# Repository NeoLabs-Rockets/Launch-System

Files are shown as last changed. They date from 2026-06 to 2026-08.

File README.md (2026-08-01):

<div align="center">

# NeoLabs-Rockets Launch System

NeoLabs Rockets Logo

**Rocket systems by NeoLabs — ESP32 launch controller + Node.js mission dashboard.**



---

[🚀 Mission Dashboard](#mission-dashboard) · [🛰️ Launch System](#launch-system)

[Compatible with NeoLabs-Rockets launch platform](https://github.com/NeoLabs-Rockets/Launch-Platform)

---

</div>

## Mission Dashboard

A single-page web app that runs on a laptop at the launch site and connects to a custom PCB over Bluetooth (BLE).

### Features

| Feature | Description |
|---|---|
| **Launch Console** | Guided 4-step wizard: Connect → Checklist → Arm → Countdown. BLE connects once and drives every view. |
| **Live BLE keepalive** | Active ping every 2 s detects silent drops; heartbeat during countdown proves the link every 700 ms. |
| **Weather & airspace** | Live wind, temperature, precipitation, and ADS-B aircraft corridor check with GO / HOLD / NO-GO badge. |
| **Location Finder** | OSM-based candidate scorer — rates grid points against roads, highways (big exclusion), settlements, power lines, water, trees, airports, and open fields. Green-only results on the map; links open Google Earth satellite view. |
| **Camera overlay** | Cinematic broadcast HUD with live T−countdown ring (bottom-right), T+ elapsed after ignition, BLE and weather telemetry. |
| **Cross-device camera** | Phone subscribes to the laptop's SSE stream and receives the countdown + BLE state in real time — no BLE on the phone needed. |



---

## Launch System

BLE launch controller — see [`/LaunchSystem`](LaunchSystem/).




One-layer PCB - no bridges

---

<div align="center">

*Made with ❤️ by [Neo](https://github.com/neooriginal) · [NeoLabs Systems](https://github.com/NeoLabs-Systems)*

</div>

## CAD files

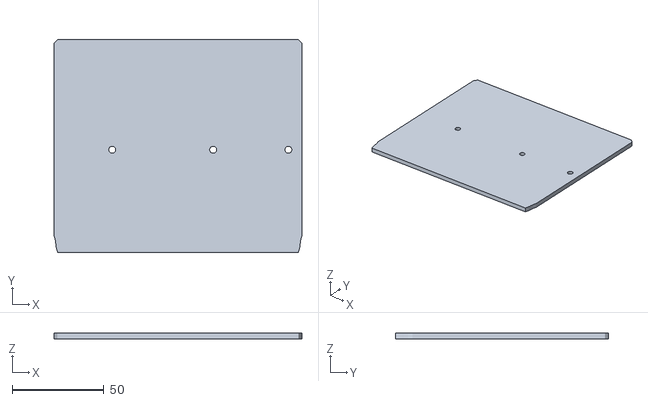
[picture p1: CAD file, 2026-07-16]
LaunchSystem/LID-optional.stl
135.1 x 116.1 x 3.00

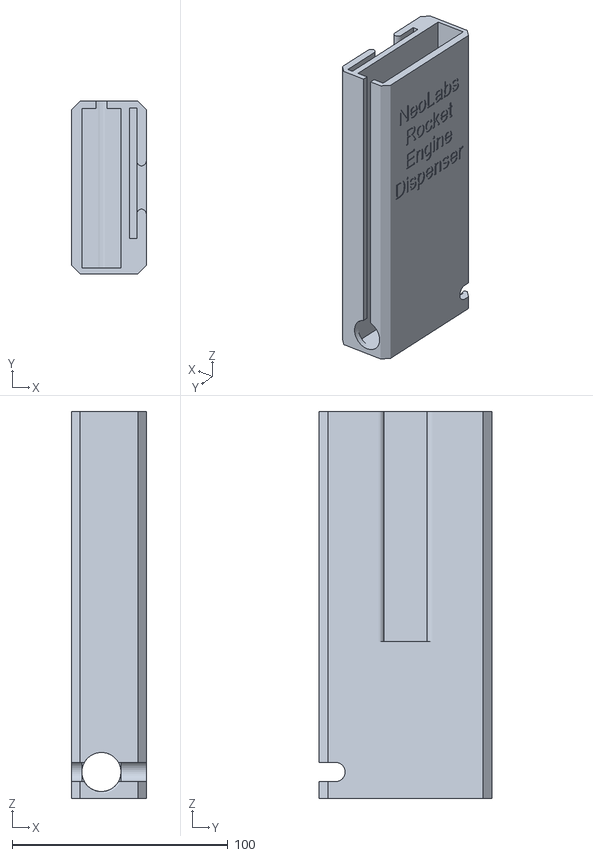
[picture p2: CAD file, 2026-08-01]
Rocket-Engine-Dispenser.stl
34.7 x 80.0 x 179.4

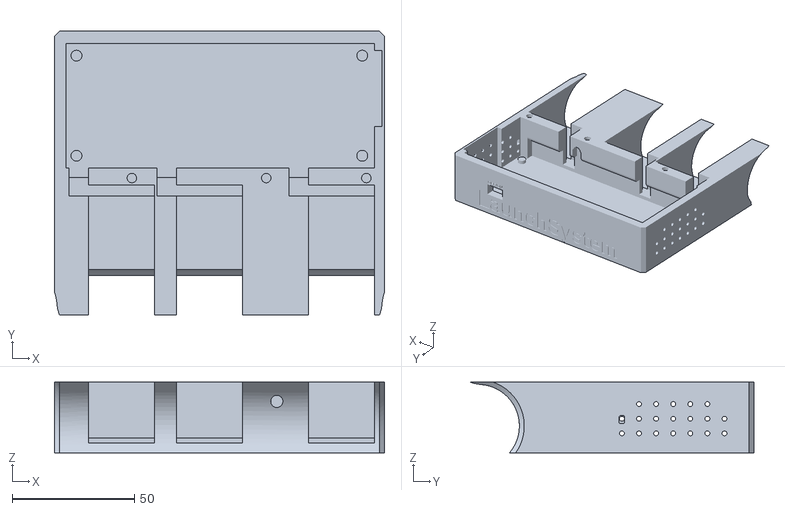
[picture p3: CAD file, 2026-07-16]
LaunchSystem/Body.stl
135.1 x 116.1 x 29.0

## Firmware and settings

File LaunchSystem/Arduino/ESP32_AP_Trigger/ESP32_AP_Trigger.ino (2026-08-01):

/* NeoLabs Rockets launch controller — BLE only. */
#include <NimBLEDevice.h>
#include <Adafruit_NeoPixel.h>
#include <Update.h>
#include <esp_ota_ops.h>
#include <mbedtls/sha256.h>

#define RELAY_PIN 23
#define CONTINUITY_PIN 34
#define CONTINUITY_ACTIVE_LEVEL LOW
#define STATUS_LED_PIN 26
#define ARM_PIN -1
#define BUZZER_PIN 33
#define TEMPERATURE_PIN 35
#define LAUNCH_CODE "123456"  // must match MissionDashboard LAUNCH_CODE
#define MAX_ATTEMPTS 10
#define TRIGGER_MS 2000UL
#define COUNTDOWN_TIMEOUT_MS 3000UL
#define CONTINUITY_DEBOUNCE_MS 60UL
#define TEMPERATURE_SAMPLE_INTERVAL_MS 1000UL
#define NTC_SAMPLE_COUNT 16
#define NTC_SUPPLY_MV 3300.0f
#define NTC_FIXED_RESISTOR_OHMS 10000.0f
#define NTC_NOMINAL_RESISTANCE_OHMS 10000.0f
#define NTC_NOMINAL_TEMPERATURE_K 298.15f
#define NTC_BETA 3950.0f
#define MAX_SAFE_TEMPERATURE_C 40.0f
#define BUZZER_MIN_FREQUENCY_HZ 1800U
#define BUZZER_MAX_FREQUENCY_HZ 4200U
#define BUZZER_FREQUENCY_STEP_HZ 120U
#define BUZZER_STEP_INTERVAL_MS 25UL
#define BUZZER_DISARM_MS 700UL
#define BUZZER_ARM_MS 900UL
#define BUZZER_TRIGGER_MS 1600UL
#define OTA_IDLE_TIMEOUT_MS 15000UL
#define OTA_REBOOT_DELAY_MS 1200UL
#define OTA_PROGRESS_INTERVAL_BYTES 2560UL

#ifndef FIRMWARE_VERSION
#define FIRMWARE_VERSION "3.0.0"
#endif

static NimBLEUUID SERVICE_UUID("8f3a0001-7b2f-4f8a-9d0e-0c5b6f0a1000");
static NimBLEUUID COMMAND_UUID("8f3a0002-7b2f-4f8a-9d0e-0c5b6f0a1000");
static NimBLEUUID STATUS_UUID ("8f3a0003-7b2f-4f8a-9d0e-0c5b6f0a1000");
static NimBLEUUID OTA_CONTROL_UUID("8f3a0004-7b2f-4f8a-9d0e-0c5b6f0a1000");
static NimBLEUUID OTA_DATA_UUID   ("8f3a0005-7b2f-4f8a-9d0e-0c5b6f0a1000");
static NimBLEUUID OTA_STATUS_UUID ("8f3a0006-7b2f-4f8a-9d0e-0c5b6f0a1000");
static const char BLE_NAME[] = "NeoLabs Launch Controller";
static const char CURRENT_FIRMWARE_VERSION[] = FIRMWARE_VERSION;

NimBLECharacteristic* statusChar = nullptr;
NimBLECharacteristic* otaStatusChar = nullptr;
Adafruit_NeoPixel statusPixel(1, STATUS_LED_PIN, NEO_GRB + NEO_KHZ800);
bool armed = false, firing = false, countdown = false, locked = false;
bool continuity = false, continuityRaw = false, continuityOverride = false;
bool temperatureOverride = false;
bool otaActive = false, otaShaInitialized = false;
float temperatureC = NAN;
unsigned long triggerStarted = 0, lastHeartbeat = 0, lastNotify = 0, continuityChangedAt = 0;
unsigned long lastTemperatureSampleAt = 0;
unsigned long buzzerStopsAt = 0, nextBuzzerStepAt = 0;
uint16_t buzzerFrequencyHz = BUZZER_MIN_FREQUENCY_HZ;
int16_t buzzerFrequencyStepHz = BUZZER_FREQUENCY_STEP_HZ;
uint32_t currentStatusPixelColor = UINT32_MAX;
uint32_t otaExpectedSize = 0, otaReceived = 0, otaLastReported = 0;
unsigned long otaLastActivityAt = 0, otaRebootAt = 0;
uint16_t otaConnectionHandle = BLE_HS_CONN_HANDLE_NONE;
int attempts = 0, connectedCount = 0;
String ownerSid, lastError, otaExpectedSha, otaVersion, otaState = "idle", otaError;
mbedtls_sha256_context otaShaContext;

#ifdef CONFIG_APP_ROLLBACK_ENABLE
// Keep a freshly installed image pending until setup has made the launch output
// safe and successfully brought BLE back online. A reset before that point lets
// the ESP32 bootloader restore the previous OTA slot.
bool verifyRollbackLater() { return true; }
#endif

String jsonString(const String& src, const char* key) {
  String pattern = String("\"") + key + "\":\"";
  int start = src.indexOf(pattern);
  if (start < 0) return "";
  start += pattern.length();
  int end = src.indexOf('"', start);
  return end < 0 ? "" : src.substring(start, end);
}

int jsonInt(const String& src, const char* key, int fallback) {
  String pattern = String("\"") + key + "\":";
  int start = src.indexOf(pattern);
  if (start < 0) return fallback;
  start += pattern.length();
  while (start < (int)src.length() && src[start] == ' ') start++;
  int end = start;
  while (end < (int)src.length() && isDigit(src[end])) end++;
  return end == start ? fallback : src.substring(start, end).toInt();
}

bool validSha256(const String& value) {
  if (value.length() != 64) return false;
  for (size_t i = 0; i < value.length(); i++) {
    const char c = value[i];
    if (!isDigit(c) && !(c >= 'a' && c <= 'f') && !(c >= 'A' && c <= 'F')) return false;
  }
  return true;
}

bool validFirmwareVersion(const String& value) {
  if (value.length() == 0 || value.length() > 63 || !isAlphaNumeric(value[0])) return false;
  for (size_t i = 1; i < value.length(); i++) {
    const char c = value[i];
    if (!isAlphaNumeric(c) && c != '.' && c != '_' && c != '+' && c != '-') return false;
  }
  return true;
}

void publishOtaStatus() {
  if (!otaStatusChar) return;
  char data[180];
  snprintf(data, sizeof(data),
    "{\"state\":\"%s\",\"received\":%lu,\"total\":%lu,\"error\":\"%s\",\"version\":\"%s\"}",
    otaState.c_str(), (unsigned long)otaReceived, (unsigned long)otaExpectedSize,
    otaError.c_str(), otaVersion.c_str());
  otaStatusChar->setValue((uint8_t*)data, strlen(data));
  otaStatusChar->notify();
}

void resetOtaState(const char* state, const char* error = "") {
  if (Update.isRunning()) Update.abort();
  if (otaShaInitialized) {
    mbedtls_sha256_free(&otaShaContext);
    otaShaInitialized = false;
  }
  otaActive = false;
  otaExpectedSize = 0;
  otaReceived = 0;
  otaLastReported = 0;
  otaConnectionHandle = BLE_HS_CONN_HANDLE_NONE;
  otaExpectedSha = "";
  otaVersion = "";
  otaState = state;
  otaError = error;
  publishOtaStatus();
}

void failOta(const char* error) {
  resetOtaState("error", error);
  lastError = "ota_failed";
  publishStatus();
}

void startBuzzer(unsigned long durationMs) {
  const unsigned long now = millis();
  buzzerFrequencyHz = BUZZER_MIN_FREQUENCY_HZ;
  buzzerFrequencyStepHz = BUZZER_FREQUENCY_STEP_HZ;
  tone(BUZZER_PIN, buzzerFrequencyHz);
  nextBuzzerStepAt = now + BUZZER_STEP_INTERVAL_MS;
  buzzerStopsAt = now + durationMs;
}

float readNtcTemperatureC() {
  uint32_t millivoltSum = 0;
  for (uint8_t i = 0; i < NTC_SAMPLE_COUNT; i++) millivoltSum += analogReadMilliVolts(TEMPERATURE_PIN);
  const float millivolts = millivoltSum / (float)NTC_SAMPLE_COUNT;
  if (millivolts <= 5.0f || millivolts >= NTC_SUPPLY_MV - 5.0f) return NAN;
  const float resistance = NTC_FIXED_RESISTOR_OHMS * millivolts / (NTC_SUPPLY_MV - millivolts);
  const float inverseKelvin = (1.0f / NTC_NOMINAL_TEMPERATURE_K)
    + logf(resistance / NTC_NOMINAL_RESISTANCE_OHMS) / NTC_BETA;
  const float sample = 1.0f / inverseKelvin - 273.15f;
  return sample < -55.0f || sample > 125.0f ? NAN : sample;
}

bool temperatureInterlockActive() {
  return !temperatureOverride && !isnan(temperatureC) && temperatureC >= MAX_SAFE_TEMPERATURE_C;
}

void setStatusPixel(uint8_t red, uint8_t green, uint8_t blue) {
  const uint32_t color = statusPixel.Color(red, green, blue);
  if (color == currentStatusPixelColor) return;
  currentStatusPixelColor = color;
  statusPixel.setPixelColor(0, color);
  statusPixel.show();
}

void safeStop(const char* reason) {
  armed = false;
  countdown = false;
  firing = false;
  continuityOverride = false;
  temperatureOverride = false;
  ownerSid = "";
  lastError = reason;
  digitalWrite(RELAY_PIN, LOW);
  noTone(BUZZER_PIN);
  buzzerStopsAt = 0;
  nextBuzzerStepAt = 0;
}

void publishStatus() {
  if (!statusChar) return;
  char data[220];
  char temperatureValue[16];
  if (isnan(temperatureC)) strcpy(temperatureValue, "null");
  else snprintf(temperatureValue, sizeof(temperatureValue), "%.2f", temperatureC);
  snprintf(data, sizeof(data),
    "{\"a\":%d,\"f\":%d,\"c\":%d,\"l\":%d,\"q\":%d,\"b\":%d,\"t\":%s,\"p\":%d,\"left\":%d,\"n\":%d,\"u\":%lu,\"e\":\"%s\",\"v\":\"%s\"}",
    armed, firing, countdown, locked, continuity, continuityOverride, temperatureValue, temperatureOverride,
    locked ? 0 : MAX_ATTEMPTS - attempts, connectedCount, millis(), lastError.c_str(), CURRENT_FIRMWARE_VERSION);
  statusChar->setValue((uint8_t*)data, strlen(data));
  statusChar->notify();
  lastNotify = millis();
}

class ServerCallbacks : public NimBLEServerCallbacks {
  void onConnect(NimBLEServer*, NimBLEConnInfo&) override {
    connectedCount++;
    publishStatus();
  }
  void onDisconnect(NimBLEServer*, NimBLEConnInfo& connInfo, int) override {
    if (connectedCount > 0) connectedCount--;
    if (otaActive && connInfo.getConnHandle() == otaConnectionHandle) resetOtaState("aborted", "disconnected");
    if (armed || countdown || continuityOverride || temperatureOverride) safeStop("owner_lost");
    else ownerSid = "";
    NimBLEDevice::getAdvertising()->start();
    publishStatus();
  }
};

class CommandCallbacks : public NimBLECharacteristicCallbacks {
  void onWrite(NimBLECharacteristic* characteristic, NimBLEConnInfo&) override {
    String body = characteristic->getValue().c_str();
    String cmd = jsonString(body, "cmd"), sid = jsonString(body, "sid");
    lastError = "";

    if (cmd == "status") {
      publishStatus();
      return;
    }
    if (otaActive || otaRebootAt) { lastError = "update_active"; publishStatus(); return; }
    if (cmd == "abort" || cmd == "disarm") { safeStop(""); startBuzzer(BUZZER_DISARM_MS); publishStatus(); return; }
    if (cmd == "auth") {
      lastError = jsonString(body, "code") == LAUNCH_CODE ? "auth_ok" : "auth_failed";
      publishStatus();
      return;
    }
    if (locked) { lastError = "locked"; publishStatus(); return; }

    if (cmd == "continuity_override") {
      if (firing || countdown) { lastError = "trigger_active"; publishStatus(); return; }
      if (ownerSid.length() && ownerSid != sid) { lastError = "not_owner"; publishStatus(); return; }
      const bool enabled = jsonInt(body, "enabled", 0) == 1;
      if (enabled) {
        continuityOverride = true;
        ownerSid = sid;
      } else if (armed && !continuity) {
        safeStop("continuity_lost");
      } else {
        continuityOverride = false;
        if (!armed) ownerSid = "";
      }
      publishStatus();
      return;
    }

    if (cmd == "temperature_override") {
      if (firing || countdown) { lastError = "trigger_active"; publishStatus(); return; }
      if (ownerSid.length() && ownerSid != sid) { lastError = "not_owner"; publishStatus(); return; }
      const bool enabled = jsonInt(body, "enabled", 0) == 1;
      if (enabled) {
        temperatureOverride = true;
        ownerSid = sid;
      } else if (armed && !isnan(temperatureC) && temperatureC >= MAX_SAFE_TEMPERATURE_C) {
        safeStop("over_temperature");
      } else {
        temperatureOverride = false;
        if (!armed) ownerSid = "";
      }
      publishStatus();
      return;
    }

    if (cmd == "arm") {
      if (ownerSid.length() && ownerSid != sid) { lastError = "not_owner"; publishStatus(); return; }
      if (temperatureInterlockActive()) { lastError = "over_temperature"; publishStatus(); return; }
      if (!continuity && !continuityOverride) { lastError = "no_continuity"; publishStatus(); return; }
      attempts = 0;
      ownerSid = sid;
      armed = true;
      countdown = false;
      startBuzzer(BUZZER_ARM_MS);
      publishStatus();
      return;
    }

    if (!ownerSid.length() || sid != ownerSid) { lastError = "not_owner"; publishStatus(); return; }
    if (cmd == "countdown_start") {
      if (temperatureInterlockActive()) safeStop("over_temperature");
      else if (!continuity && !continuityOverride) safeStop("continuity_lost");
      else if (!armed || firing) lastError = armed ? "trigger_active" : "not_armed";
      else { countdown = true; lastHeartbeat = millis(); }
    } else if (cmd == "heartbeat") {
      if (countdown) lastHeartbeat = millis();
    } else if (cmd == "trigger") {
      if (!armed) lastError = "not_armed";
      else if (temperatureInterlockActive()) safeStop("over_temperature");
      else if (!continuity && !continuityOverride) safeStop("continuity_lost");
      else if (!countdown || millis() - lastHeartbeat > COUNTDOWN_TIMEOUT_MS) safeStop("heartbeat_lost");
      else {
        digitalWrite(RELAY_PIN, HIGH);
        firing = true;
        triggerStarted = millis();
        armed = false;
        countdown = false;
        continuityOverride = false;
        ownerSid = "";
        startBuzzer(BUZZER_TRIGGER_MS);
      }
    } else lastError = "unknown_cmd";
    publishStatus();
  }
};

class OtaControlCallbacks : public NimBLECharacteristicCallbacks {
  void onWrite(NimBLECharacteristic* characteristic, NimBLEConnInfo& connInfo) override {
    String body = characteristic->getValue().c_str();
    const String cmd = jsonString(body, "cmd");

    if (cmd == "status") { publishOtaStatus(); return; }
    if (otaRebootAt) { publishOtaStatus(); return; }
    if (cmd == "abort") {
      if (otaActive && connInfo.getConnHandle() != otaConnectionHandle) {
        otaError = "not_owner";
        publishOtaStatus();
        return;
      }
      resetOtaState("aborted", "cancelled");
      return;
    }
    if (cmd == "begin") {
      if (otaActive || otaRebootAt) { otaError = "already_active"; publishOtaStatus(); return; }
      if (armed || firing || countdown) { otaState = "error"; otaError = "controller_not_idle"; publishOtaStatus(); return; }

      const int requestedSize = jsonInt(body, "size", 0);
      const String requestedSha = jsonString(body, "sha256");
      const String requestedVersion = jsonString(body, "version");
      if (requestedSize <= 0 || !validSha256(requestedSha) || !validFirmwareVersion(requestedVersion)) {
        otaState = "error";
        otaError = "invalid_manifest";
        publishOtaStatus();
        return;
      }

      safeStop("");
      if (!Update.begin((size_t)requestedSize, U_FLASH)) {
        otaState = "error";
        otaError = Update.errorString();
        publishOtaStatus();
        return;
      }
      mbedtls_sha256_init(&otaShaContext);
      if (mbedtls_sha256_starts_ret(&otaShaContext, 0) != 0) {
        Update.abort();
        mbedtls_sha256_free(&otaShaContext);
        otaState = "error";
        otaError = "sha_init_failed";
        publishOtaStatus();
        return;
      }
      otaShaInitialized = true;
      otaActive = true;
      otaExpectedSize = (uint32_t)requestedSize;
      otaReceived = 0;
      otaLastReported = 0;
      otaLastActivityAt = millis();
      otaConnectionHandle = connInfo.getConnHandle();
      otaExpectedSha = requestedSha;
      otaExpectedSha.toLowerCase();
      otaVersion = requestedVersion;
      otaState = "ready";
      otaError = "";
      lastError = "";
      publishOtaStatus();
      publishStatus();
      return;
    }
    if (cmd == "finish") {
      if (!otaActive || connInfo.getConnHandle() != otaConnectionHandle) {
        otaState = "error";
        otaError = otaActive ? "not_owner" : "not_active";
        publishOtaStatus();
        return;
      }
      if (otaReceived != otaExpectedSize) { failOta("incomplete"); return; }

      uint8_t digest[32];
      if (!otaShaInitialized || mbedtls_sha256_finish_ret(&otaShaContext, digest) != 0) {
        failOta("sha_finish_failed");
        return;
      }
      mbedtls_sha256_free(&otaShaContext);
      otaShaInitialized = false;
      char actualSha[65];
      for (uint8_t i = 0; i < sizeof(digest); i++) snprintf(actualSha + i * 2, 3, "%02x", digest[i]);
      actualSha[64] = '\0';
      if (otaExpectedSha != actualSha) { failOta("sha_mismatch"); return; }
      if (!Update.end(false)) { failOta(Update.errorString()); return; }

      otaActive = false;
      otaState = "complete";
      otaError = "";
      publishOtaStatus();
      otaRebootAt = millis() + OTA_REBOOT_DELAY_MS;
      return;
    }
    otaState = "error";
    otaError = "unknown_command";
    publishOtaStatus();
  }
};

class OtaDataCallbacks : public NimBLECharacteristicCallbacks {
  void onWrite(NimBLECharacteristic* characteristic, NimBLEConnInfo& connInfo) override {
    const std::string value = characteristic->getValue();
    if (!otaActive || connInfo.getConnHandle() != otaConnectionHandle || value.size() <= 4) return;
    const uint8_t* bytes = (const uint8_t*)value.data();
    const uint32_t offset = (uint32_t)bytes[0] | ((uint32_t)bytes[1] << 8)
      | ((uint32_t)bytes[2] << 16) | ((uint32_t)bytes[3] << 24);
    const size_t payloadSize = value.size() - 4;
    if (offset < otaReceived) { publishOtaStatus(); return; }
    if (offset != otaReceived || otaReceived + payloadSize > otaExpectedSize) { failOta("invalid_offset"); return; }
    if (Update.write((uint8_t*)bytes + 4, payloadSize) != payloadSize) { failOta(Update.errorString()); return; }
    if (mbedtls_sha256_update_ret(&otaShaContext, bytes + 4, payloadSize) != 0) { failOta("sha_update_failed"); return; }
    otaReceived += payloadSize;
    otaLastActivityAt = millis();
    otaState = "receiving";
    if (otaReceived == otaExpectedSize || otaReceived - otaLastReported >= OTA_PROGRESS_INTERVAL_BYTES) {
      otaLastReported = otaReceived;
      publishOtaStatus();
    }
  }
};
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
void loop() {
  const unsigned long now = millis();
  if (otaActive && now - otaLastActivityAt > OTA_IDLE_TIMEOUT_MS) failOta("timeout");
  if (otaRebootAt && (long)(now - otaRebootAt) >= 0) {
    otaRebootAt = 0;
    ESP.restart();
  }
  if (now - lastTemperatureSampleAt >= TEMPERATURE_SAMPLE_INTERVAL_MS) {
    lastTemperatureSampleAt = now;
    temperatureC = readNtcTemperatureC();
    if (temperatureInterlockActive() && (armed || countdown || firing)) {
      safeStop("over_temperature");
      startBuzzer(BUZZER_TRIGGER_MS);
    } else if (!temperatureInterlockActive() && lastError == "over_temperature") lastError = "";
    publishStatus();
  }
  // The energized relay changes the continuity circuit, so GPIO34 is not a
  // valid measurement during the trigger pulse. Preserve the last verified
  // value until the relay closes, then restart the normal debounce window.
  if (!firing) {
    const bool sampledContinuity = digitalRead(CONTINUITY_PIN) == CONTINUITY_ACTIVE_LEVEL;
    if (sampledContinuity != continuityRaw) {
      continuityRaw = sampledContinuity;
      continuityChangedAt = now;
    } else if (continuity != continuityRaw && now - continuityChangedAt >= CONTINUITY_DEBOUNCE_MS) {
      continuity = continuityRaw;
      if (continuity) continuityOverride = false;
      if (!continuity && !continuityOverride && (armed || countdown)) {
        safeStop("continuity_lost");
        startBuzzer(BUZZER_DISARM_MS);
      }
      else if (continuity && (lastError == "no_continuity" || lastError == "continuity_lost")) lastError = "";
      publishStatus();
    }
  }
  if (firing && now - triggerStarted >= TRIGGER_MS) {
    digitalWrite(RELAY_PIN, LOW);
    firing = false;
    continuityRaw = digitalRead(CONTINUITY_PIN) == CONTINUITY_ACTIVE_LEVEL;
    continuityChangedAt = now;
    publishStatus();
  }
  if (countdown && now - lastHeartbeat > COUNTDOWN_TIMEOUT_MS) {
    safeStop("heartbeat_lost");
    publishStatus();
  }
  if (buzzerStopsAt) {
    if ((long)(now - buzzerStopsAt) >= 0) {
      noTone(BUZZER_PIN);
      buzzerStopsAt = 0;
      nextBuzzerStepAt = 0;
    } else if ((long)(now - nextBuzzerStepAt) >= 0) {
      int32_t nextFrequency = (int32_t)buzzerFrequencyHz + buzzerFrequencyStepHz;
      if (nextFrequency >= BUZZER_MAX_FREQUENCY_HZ || nextFrequency <= BUZZER_MIN_FREQUENCY_HZ) {
        buzzerFrequencyStepHz = -buzzerFrequencyStepHz;
        nextFrequency = constrain(nextFrequency, BUZZER_MIN_FREQUENCY_HZ, BUZZER_MAX_FREQUENCY_HZ);
      }
      buzzerFrequencyHz = (uint16_t)nextFrequency;
      tone(BUZZER_PIN, buzzerFrequencyHz);
      nextBuzzerStepAt = now + BUZZER_STEP_INTERVAL_MS;
    }
  }
  // NeoPixel status: red = firing/fault, amber = armed/countdown/bypass,
  // blue heartbeat = waiting for BLE, green = connected and ready.
  uint8_t red = 0, green = 0, blue = 0;
  if (firing) red = 140;
  else if (otaActive) { red = 35; blue = 100; }
  else if (temperatureInterlockActive()) { red = 110; blue = 12; }
  else if (countdown && (now / 100) % 2) { red = 120; green = 28; }
  else if (armed) { red = 90; green = 18; }
  else if (continuityOverride || temperatureOverride) { red = 55; green = 28; }
  else if (!continuity) {
    const unsigned long phase = now % 1200;
    if (phase < 90 || (phase >= 180 && phase < 270)) red = 100;
  } else if (connectedCount == 0) {
    if (now % 2000 < 80) blue = 80;
  } else green = 32;
  setStatusPixel(red, green, blue);
  if (now - lastNotify >= 1000) publishStatus();
  delay(5);
}

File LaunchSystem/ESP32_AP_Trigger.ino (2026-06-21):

/*
  NeoLabs Rockets — Mission Control
  ─────────────────────────────────────────────────────────────────────────────
  ESP32 NodeMCU DevKit (USB-C) as WiFi Access Point with a modern web UI
  and REST API for armed-and-trigger launch control.

  Features:
    · WiFi Access Point (SSID / password configurable below)
    · NeoLabs-branded mission-control UI served from flash
    · ARM/DISARM button — trigger is gated behind arm state
    · 10-second browser countdown with TTS (Web Speech API, English)
      → "Ignition" spoken at 0; pin goes HIGH 500 ms after
    · Auto-disarm after every trigger
    · Non-blocking 800 ms HIGH pulse on TRIGGER_PIN
    · Optional status LED (5 Hz blink while firing, solid while armed)
    · Optional physical ARM toggle button

  REST API:
    GET  /api/status   → { armed, trigger_active, uptime_ms, clients }
    POST /api/arm      → { ok, armed }
    POST /api/disarm   → { ok, armed }
    POST /api/trigger  → { ok } | { ok, error }

  ─────────────────────────────────────────────────────────────────────────────
  PIN ASSIGNMENTS — change only here
*/
#define TRIGGER_PIN   26    // Output: 800 ms HIGH pulse on fire
#define STATUS_LED     2    // Status LED  (-1 = disabled)  GPIO 2 = onboard
#define ARM_PIN       25    // Physical ARM toggle (-1 = disabled)
                            // Wiring: button between ARM_PIN and GND (INPUT_PULLUP)

// Network
#define AP_SSID   "NeoLabs-Rockets"
#define AP_PASS   "launch1234"           // min. 8 characters (WPA2)

// Timing
#define TRIGGER_MS   800UL   // relay pulse duration in milliseconds
#define DEBOUNCE_MS   50UL   // physical button debounce
// ─────────────────────────────────────────────────────────────────────────────

#include <WiFi.h>
#include <WebServer.h>

WebServer server(80);

bool          armed         = false;
bool          triggerActive = false;
unsigned long triggerStart  = 0;

int           lastBtnRead   = HIGH;
unsigned long lastDebounce  = 0;

// ─── Embedded web UI ─────────────────────────────────────────────────────────
static const char HTML_PAGE[] = R"HTMLPAGE(<!DOCTYPE html>
<html lang="en">
<head>
<meta charset="UTF-8">
<meta name="viewport" content="width=device-width,initial-scale=1">
<title>NeoLabs Rockets · Mission Control</title>
<style>
:root{
  --bg:#070b16;--bg2:#0c1224;--panel:rgba(18,26,48,.55);--border:#1b2746;
  --blue:#4d9fff;--blue-d:#2d6fe0;--ice:#9fd4ff;--glow:#5ab8ff;
  --green:#36f0a0;--red:#ff4a3d;--amber:#ffb347;
  --text:#dbe7ff;--muted:#5b6a8f;--silver:#c9d6ef;
  --font:'Segoe UI',system-ui,-apple-system,'Helvetica Neue',sans-serif;
}
*{margin:0;padding:0;box-sizing:border-box}
body{
  min-height:100vh;color:var(--text);font-family:var(--font);
  background:
    radial-gradient(1100px 700px at 50% -10%,rgba(45,111,224,.16),transparent 60%),
    radial-gradient(800px 500px at 85% 110%,rgba(40,90,200,.10),transparent 55%),
    var(--bg);
  position:relative;overflow-x:hidden;
}
/* faint star field */
body::before{content:'';position:fixed;inset:0;z-index:0;pointer-events:none;opacity:.5;
  background-image:radial-gradient(1px 1px at 20% 30%,rgba(255,255,255,.5),transparent),
    radial-gradient(1px 1px at 70% 65%,rgba(255,255,255,.35),transparent),
    radial-gradient(1px 1px at 40% 80%,rgba(255,255,255,.3),transparent),
    radial-gradient(1px 1px at 88% 18%,rgba(255,255,255,.4),transparent),
    radial-gradient(1px 1px at 12% 70%,rgba(255,255,255,.3),transparent);}

/* ── Header / wordmark ── */
header{position:sticky;top:0;z-index:50;display:flex;justify-content:space-between;align-items:center;
  padding:16px 26px;border-bottom:1px solid var(--border);
  background:linear-gradient(180deg,rgba(7,11,22,.92),rgba(7,11,22,.6));backdrop-filter:blur(14px)}
.brand{display:flex;align-items:center;gap:14px}
.hole{width:38px;height:38px;flex-shrink:0;filter:drop-shadow(0 0 8px rgba(90,184,255,.55))}
.wm{font-size:1.15em;letter-spacing:.42em;font-weight:600;line-height:1}
.wm .neo{background:linear-gradient(180deg,#fff,var(--silver));-webkit-background-clip:text;background-clip:text;color:transparent}
.wm .labs{background:linear-gradient(180deg,var(--ice),var(--blue));-webkit-background-clip:text;background-clip:text;color:transparent}
.tag{font-size:.6em;letter-spacing:.34em;color:var(--muted);margin-top:6px;text-transform:uppercase}
.hdr-dots{display:flex;gap:7px}
.dot{width:8px;height:8px;border-radius:50%;background:var(--border);transition:all .4s}
.on-blue{background:var(--blue)!important;box-shadow:0 0 9px var(--blue)!important}
.on-red{background:var(--red)!important;box-shadow:0 0 9px var(--red)!important;animation:dpulse 1s infinite}
.on-amber{background:var(--amber)!important;box-shadow:0 0 9px var(--amber)!important}
@keyframes dpulse{0%,100%{opacity:1}50%{opacity:.3}}

main{max-width:840px;margin:0 auto;padding:30px 18px;position:relative;z-index:1}
.lbl{font-size:.62em;letter-spacing:.28em;color:var(--muted);text-transform:uppercase;margin:0 0 10px 4px}

.card{background:var(--panel);border:1px solid var(--border);border-radius:16px;padding:22px;
  margin-bottom:22px;position:relative;backdrop-filter:blur(8px);
  box-shadow:0 14px 40px rgba(0,0,0,.35),inset 0 1px 0 rgba(255,255,255,.03);
  transition:border-color .4s,box-shadow .4s}

.armed-warn{display:none;margin-bottom:16px;border:1px solid rgba(255,74,61,.5);border-radius:10px;
  padding:10px 14px;font-size:.7em;letter-spacing:.28em;color:var(--red);text-align:center;
  background:rgba(255,74,61,.06);animation:warn-pulse 1.3s infinite}
.armed-warn.show{display:block}
@keyframes warn-pulse{0%,100%{opacity:1}50%{opacity:.45}}

.status-badge{display:flex;align-items:center;gap:12px;font-size:.98em;margin-bottom:18px;font-weight:500}
.ind{width:11px;height:11px;border-radius:50%;flex-shrink:0;transition:all .4s}
.stats{display:grid;grid-template-columns:repeat(4,1fr);gap:10px}
@media(max-width:520px){.stats{grid-template-columns:repeat(2,1fr)}}
.stat{background:rgba(7,11,22,.5);border:1px solid var(--border);border-radius:10px;padding:12px 14px}
.sk{font-size:.58em;color:var(--muted);letter-spacing:.14em;text-transform:uppercase}
.sv{font-size:.95em;margin-top:4px;color:var(--silver);font-variant-numeric:tabular-nums}
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

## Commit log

2026-06-22 fix and 3d model
    [NeoLabs-Rocket-LaunchSystem.obj]
2026-06-22 fixed 3d model
    [NeoLabs-Rocket-LaunchSystem.obj]
2026-06-24 update models
    [Body1.stl, Body2.stl, NeoLabs-Rocket-LaunchSystem.3mf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]
2026-07-12 Switch launch control to BLE ownership
    Converts the ESP32 controller to BLE-only operation and updates the Mission Dashboard to coordinate a single BLE owner with shared state, authorization, and remote command relaying. Removes the embed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
2026-07-12 Implement shared BLE ownership and auth flow
    Add a shared BLE ownership model and robust auth/command handshake. Server: track SSE clients with clientId/authorization, allow targeted SSE emits, bind sessions to BLE owner, invalidate sessions when owner changes, rate-limit failed auth attempts, and close unauthorized SSE clients when an owner appears. Add pending remote-command lifecycle and safe command IDs. Client: introduce NeoAuthReady, improved join-code dialog with server validation, claimOwnerSession flow, pendingRemoteCommands with timeouts, remove storing/forwarding plain launch codes, format controller errors, and UI tweaks (control-mode, names, script order). Arduino: minor safeSto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
    [ESP32_AP_Trigger.ino]
2026-07-12 Add finder analysis and recording cache
    Move OSM scoring to the server, add cached finder analysis with faster feature indexing, and surface server link status in the launch dashboard. Also add resilient dual-stream camera recording with b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
2026-07-12 Add multi-device BLE launch synchronization
    Enable camera and dashboard clients to receive synchronized countdown and launch events from BLE controller. Implement write chaining for reliable BLE communication, shared state tracking, and proper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
2026-07-12 Improve launch auth and mobile UX
    Make launch control fall back to explicit authorization when the BLE owner is unavailable, surface firmware version in the dashboard, add camera lens selection with ultrawide handling, and tighten mobile layouts for the dashboard and launch dialog.
    [ESP32_AP_Trigger.ino]
2026-07-12 Add resilient NeoBleLink and refactor sync
    Introduce a new resilient Web Bluetooth transport (MissionDashboard/ble-link.js) and a server sync/owner lease module (MissionDashboard/launch-sync.js), wire them into the Launch Console, and remove 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
2026-07-12 Improve BLE ownership, wake-lock, and sync resilience
    Multiple fixes and features to make BLE ownership, remote relay, and shared-state syncing more robust:
    - Ensure true activity is recorded only on valid BLE controller responses (move lastActivityAt to notify handler).
    - Prevent duplicate client identity across tabs via a probe/reservation channel and per-tab instance id; set CLIENT_ID early and delay sync until resolved.
    - Add queuing for remote commands to avoid interleaved BLE status reads and surface friendlier remote-command errors.
    - Implement screen wake-lock support for the launch owner (ensure/release/sync, preflight during user-initiated actions, retry handling, and UI integrati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
2026-07-13 Improve launch and recording flows
    Tighten launch countdown handling on Chrome/macOS by serializing BLE heartbeats, ignoring stale countdown-off status, and keeping speech utterances alive longer. Also split the green-screen recording into a separate user-triggered download with a dedicated button and deferred cache cleanup.
2026-07-13 Show launch state tile and default ultrawide lens
    Add a new launchStateTile and use it in the HUD so the top-left telemetry shows a derived launch state instead of a plain LINK label. Introduce cameraControllerStatus (populated from BLE status) and 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
2026-07-15 Add continuity interlock & dashboard support
    Firmware and UI changes to enforce ignition continuity and surface its state. Firmware bumped to 2.3.0: add GPIO39 continuity input with debounce, relay control on GPIO23, red status LED on GPIO26, and optional vibration output (disabled for input-only pins). The controller now blocks arming when continuity is missing and performs a safe disarm if continuity is lost; status notifications include a new `q` field for continuity. MissionDashboard updated to display continuity state, prevent arming when open, show continuity cards and messages, and map controller errors for continuity cases. CSS adds styles for continuity cards and layout tweaks; READ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
    [ESP32_AP_Trigger.ino]
2026-07-15 Add continuity override (firmware + UI)
    Introduce a temporary continuity interlock bypass for troubleshooting and controlled launches.
    Firmware (ESP32_AP_Trigger.ino): bump firmware to 2.4.0 and add continuityOverride state that can be toggled via a new BLE command (continuity_override). The status payload now includes a new field '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
    MissionDashboard (JS/HTML/CSS): add UI support for toggling the continuity override from both the local and dash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
2026-07-15 Refactor TTS handling; update ESP32 config
    Centralize countdown speech in MissionDashboard: bluetooth.js now owns audible TTS via announceLaunchEvent, consolidating speech logic, renaming variables, and removing legacy audio-context beeps. Camera-side code (camera.js) no longer performs global speech synthesis and only emits recorded overlay cues to avoid duplicate/competing announcements. Shared countdown events are announced to camera when appropriate.
    ESP32 firmware changes: CONTINUITY_ACTIVE_LEVEL flipped to LOW, VIBRATION_PIN moved to GPIO25 with proper availability macros, log text generalized, and firmware version bumped to 2.6.1. These hardware tweaks fix input/pull-level assumption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
    [ESP32_AP_Trigger.ino]
2026-07-16 Use NTC thermistor and NeoPixel status LED
    Replace the DS18B20 OneWire temperature sensor with a 10 kΩ B3950 NTC on ADC (GPIO35) and swap the single red LED for an Adafruit NeoPixel status pixel on GPIO26. Implement averaged millivolt ADC sampling, resistance-to-temperature conversion (Beta formula), sampling/timing constants, and status pixel helpers (setStatusPixel) with new color/state mapping. Remove OneWire/DallasTemperature usage and deps, add Adafruit NeoPixel dependency, bump firmware to 2.9.0, and simplify temperature sampling logic. Also update platformio.ini, add the ESP32_AP_Trigger .pio dir to .gitignore, and update MissionDashboard text/comments to reflect the NTC sensor and n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
    [ESP32_AP_Trigger.ino]
2026-07-16 Add PCB/GERBER/STL and update buzzer sweep
    Add KiCad project files, gerber outputs and a 3D body STL for the LaunchSystem PCB (LaunchSystem.kicad_pcb/.kicad_prl/.kicad_pro/.kicad_sch and GERBERFILES plus Body.stl). Update ESP32 firmware (ESP32_AP_Trigger.ino): bump firmware to 2.9.2 and replace the fixed buzzer tone with a configurable frequency sweep (min/max/step/interval), extend buzzer durations, add state tracking for sweep steps, and update startBuzzer/safeStop/loop logic to drive the sweeping tone and properly stop it. Minor related variable additions and timing adjustments included.
    [Body.stl, LaunchSystem.kicad_pcb, LaunchSystem.kicad_sch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]
2026-07-16 Add temperature interlock and dryness metric
    Add a 40 °C temperature interlock to the ESP32 firmware (bump firmware to 3.0.0): introduce MAX_SAFE_TEMPERATURE_C, temperature checks that block arming/trigger/countdown, call safeStop and start the buzzer when exceeded, and update the status LED color. On the web dashboard, surface the interlock (disable arm/launch, show HOT badge and explanatory text), map controller over_temperature errors to readable text, and add visual styling for hot controller state. Also add a modeled "Dryness · Dry Land" metric derived from recent soil moisture, humidity and precipitation/evapotranspiration history (new evaluateDryness logic, UI card, and styles), adj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
    [ESP32_AP_Trigger.ino]
2026-07-16 Add BLE OTA support and firmware pipeline
    Introduce end-to-end Bluetooth OTA and CI for firmware: add a GitHub Actions workflow to build PlatformIO firmware, create a firmware-version file, and upload a rolling release. Add scripts/create_firmware_manifest.py to generate validated manifests and pin PlatformIO/platform and libraries in platformio.ini. Implement BLE OTA in the ESP32 sketch (new OTA control/data/status characteristics, SHA-256 verification, timeouts, safe apply/rollback handling and reboot), and expose firmware version from the running firmware. Update MissionDashboard: add OTA UI, BLE client OTA support (ble-link.js), frontend wiring (bluetooth.js, index.html, styles.css) and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
    [ESP32_AP_Trigger.ino]
2026-07-16 Require live BLE owner for launch transitions
    Prevent stale or offline BLE controller events from advancing the camera HUD. Changes:
    - bluetooth.js: clear persisted lastEvent on link down; ensure camera shared state is published before replaying durable launch transitions; only replay lastEvent when ownerActive; adjust countdown application to treat missing owner as inactive.
    - camera.js: restore BLE authority (ble state) before restoring any saved launch event; only accept saved/applyLaunchEvent countdown or ignition updates when there is live controller evidence (armed/countdown/trigger) to avoid starting T+ from stale events.
    - server.js: stop replaying ignition to new/offline clients (o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
2026-07-16 Update KiCad PWR section, footprints & nets
    Add KiCad lock/history ignores to .gitignore. Major PCB changes: rename nets (GPIO35 -> 3.3v), add axial resistor footprint, replace/update TO-220 footprint for L7805 and update related pads/traces/zones. Schematic updates: bump sch revision to V3, add title block/date/rev/company, reposition components/junctions/wires, add PWR section label and a resistor symbol (R2), move PWR_FLAG and connectors. Overall: layout cleanup, footprint corrections and schematic revision to reflect PWR section rework.
    [LaunchSystem.kicad_pcb, LaunchSystem.kicad_sch]
2026-07-30 overrite temperature
2026-08-02 Add optional Rocket Computer BLE & UI
    Introduce support for an optional onboard "rocket computer" BLE link and UI. Adds a standalone RocketBleLink transport (rocket-ble-link.js) with robust connect/reconnect, ping/watchdog, write queuing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
2026-08-02 Revamp launch link UI and styles
    Rework the launch link/dashboard UI and related styles, HTML, and JS to a more compact, consistent link-board/link-panel layout. index.html: replace the old dual-link grid with a two-column link-board and link-panel markup, simplify labels and copy (e.g. "Rocket"), hide legacy fields still updated by JS, and shorten several button/summary texts. bluetooth.js & rocket-computer.js: add a reusable link-badge class, toggle linked/armed states on the launch panel, preserve older class names for compatibility, and adjust rocket-computer status/labels (e.g. "FLY"/"Post-land") and camera FPS formatting so FPS is shown alongside camera when connected. styles.css: larg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
2026-08-02 Add RC Data UI and RC firmware OTA support
    Introduce a new "RC Data" tab and UI to browse/download flight telemetry and video from the rocket computer over BLE (packed into a ZIP via JSZip). Add rc-data.js to drive the UI and wire into the sh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
2026-08-06 Implement Flight Viewer UI and parsers
    Replace the old RC Data BLE download panel with a local Flight Viewer experience. Adds UI for drag/drop or picking ZIPs/folders, a player canvas, transport/scrub controls, events sidebar, charts, HUD and broadcast overlay, and export controls. Implements robust parsers for metadata, events, telemetry (with CRC-16/CCITT-FALSE verification), and length-prefixed MJPEG video, plus timeline/charting, playback engine, and chart tooltips. Updates index.html and styles, and includes a sample test-flight.zip for debugging.
